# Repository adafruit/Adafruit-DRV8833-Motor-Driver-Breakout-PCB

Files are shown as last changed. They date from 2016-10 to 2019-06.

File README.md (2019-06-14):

## Adafruit DRV8833 Motor Driver Breakout PCB

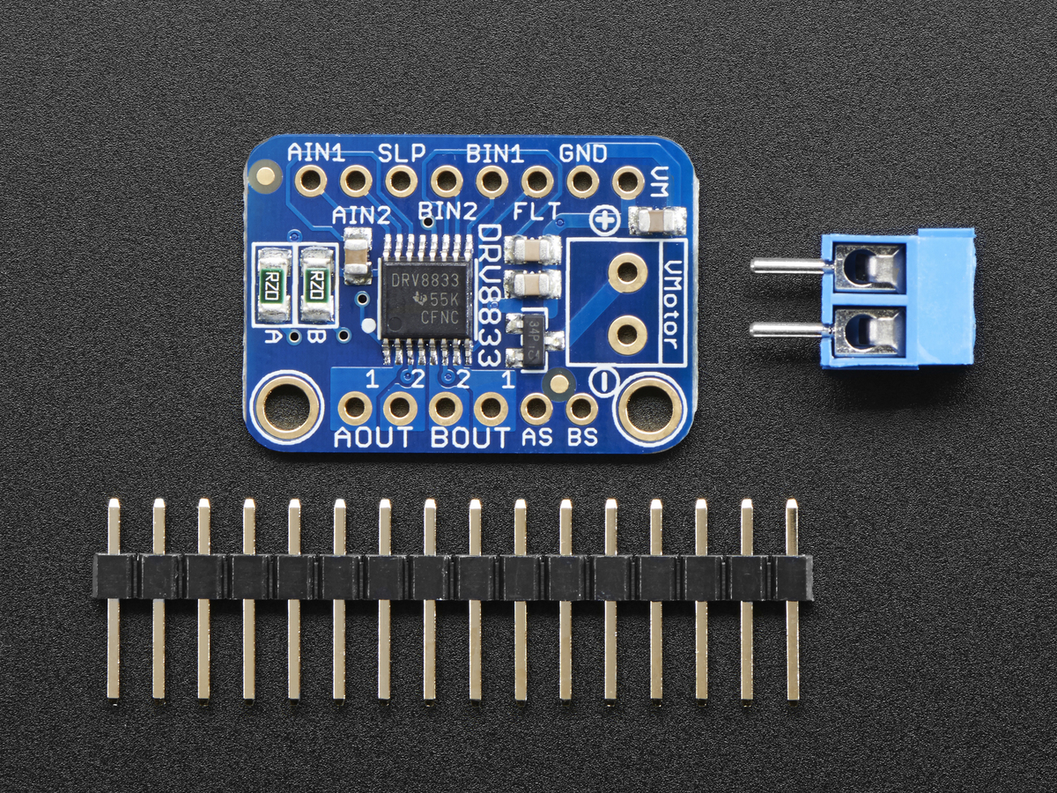
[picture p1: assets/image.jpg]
<a href="http://www.adafruit.com/products/3297"><br/>
Click here to purchase one from the Adafruit shop</a>

PCB files for the Adafurit DRV8833 Motor Driver Breakout. Format is EagleCAD schematic and board layout
* https://www.adafruit.com/product/3297

### DESCRIPTION
Spin two DC motors or step one bi-polar or uni-polar stepper with up to 1.2A per channel using the DRV8833. This motor driver chip is a nice alternative to the TB6612 driver. Like that chip, you get 2 full H-bridges, but this chip is better for low voltage uses (can run from 2.7V up to 10.8V motor power) and has built in current limiting capability. We set it up for 1A current limiting so you don't get more than 2A per chip, but you can also disable the current limiting, or change it to a different limit!

We solder on DRV8833 onto a breakout board for you here, with a polarity protection FET on the motor voltage input. Each breakout chip contains two full H-bridges (four half H-bridges). That means you can drive two DC motors bi-directionally, or one stepper motor. Just make sure they're good for about 1.2 Amp or less of current, since that's the limit of this chip. They do handle a peak of 2A but that's just for a short amount of time, if you turn off the current limiting we set. What we like most about this particular driver is that it comes with built in kick-back diodes internally so you dont have to worry about the inductive kick damaging your project or driver! You also don't have to worry as much about burning out the chip with overdriving since there is current limiting.

There's two digital inputs per H-bridge (one for each half of the bridge), you can PWM one of the inputs to control motor speed. Runs at 2.7V-10.8V logic/motor power. The motor voltage is the same as the logic voltage, but logic voltage from 2.7V or greater will work so no need to worry if you are powering the motors from 9V and using 3.3V logic. For higher voltages, check out the TB6612. For much higher voltages and currents check out the DRV8871!

### License

Adafruit invests time and resources providing this open source design, please support Adafruit and open-source hardware by purchasing products from [Adafruit.com](https://www.adafruit.com)!

Creative Commons Attribution, Share-Alike license, check license.txt for more information All text above must be included in any redistribution - 
See license.txt for more information.

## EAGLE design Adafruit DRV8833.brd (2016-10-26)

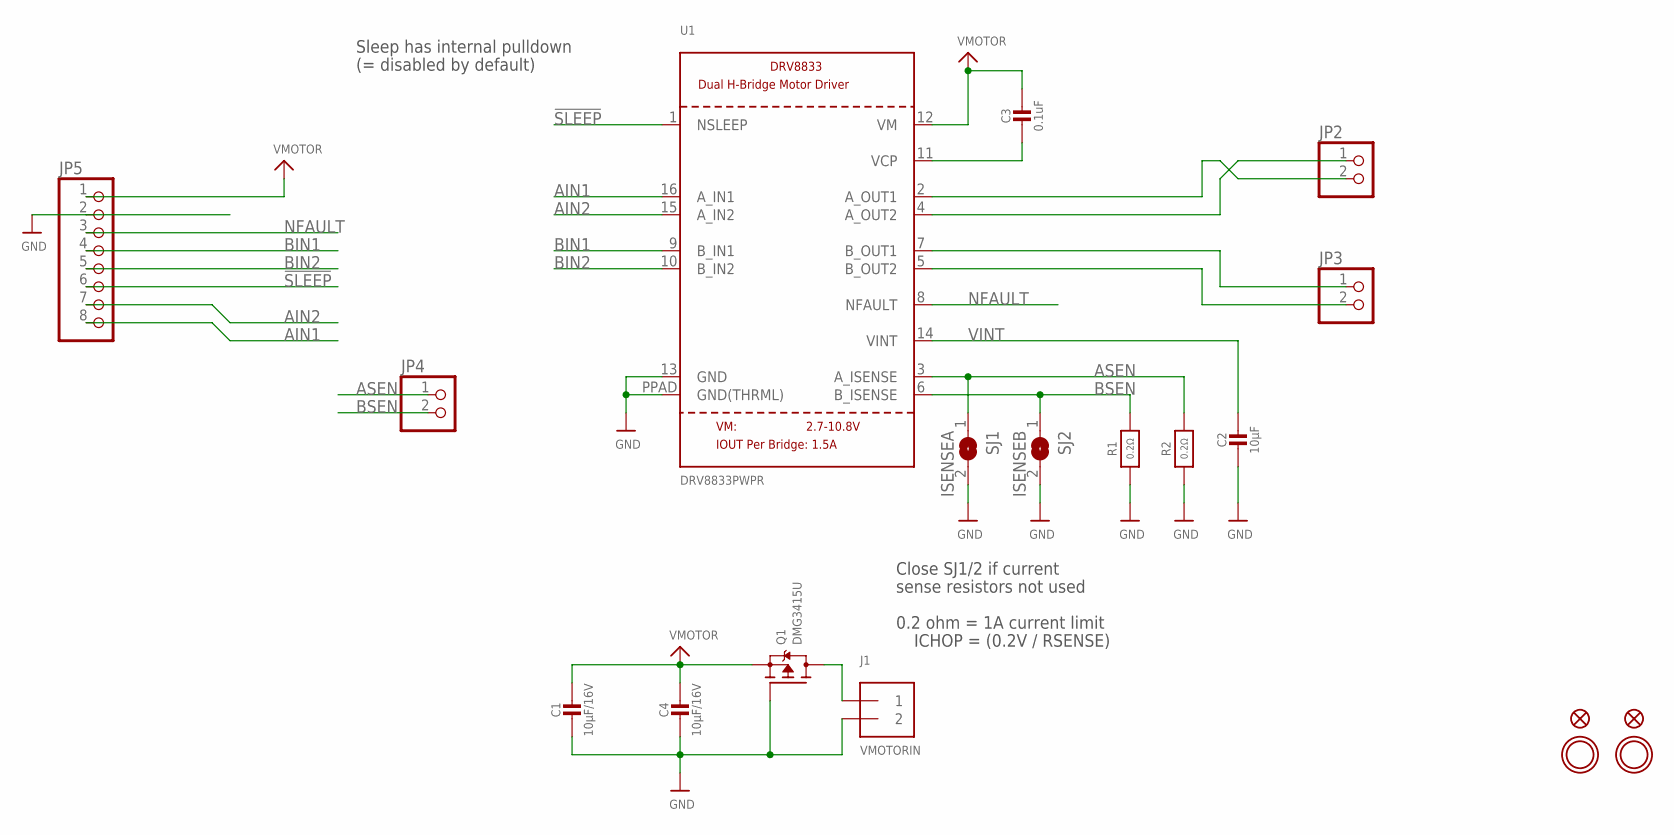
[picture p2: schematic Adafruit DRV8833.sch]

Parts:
C1, C4: 10µF/16V; 0805-NO
C2: 10µF; 0805-NO
C3: 0.1uF; 0805-NO
FID1, FID2: FIDUCIAL""; FIDUCIAL_1MM
J1: VMOTORIN; TERMBLOCK_1X2-3.5MM
JP2, JP3, JP4: HEADER-1X2ROUND; 1X02_ROUND
JP5: HEADER-1X870MIL; 1X08_ROUND_70
Q1: DMG3415U; SOT23-WIDE
R1, R2: 0.2Ω; _1206
SJ1: ISENSEA; SOLDERJUMPER_ARROW_NOPASTE
SJ2: ISENSEB; SOLDERJUMPER_ARROW_NOPASTE
U1: DRV8833PWPR; HTSSOP16
U$13, U$14: MOUNTINGHOLE2.5; MOUNTINGHOLE_2.5_PLATED

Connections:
!SLEEP: JP5.6, U1.1 (NSLEEP)
AIN1: JP5.8, U1.16 (A_IN1)
AIN2: JP5.7, U1.15 (A_IN2)
AOUT1: JP2.2, U1.2 (A_OUT1)
AOUT2: JP2.1, U1.4 (A_OUT2)
ASEN: JP4.1, R2.2, SJ1.1, U1.3 (A_ISENSE)
BIN1: JP5.4, U1.9 (B_IN1)
BIN2: JP5.5, U1.10 (B_IN2)
BOUT1: JP3.1, U1.7 (B_OUT1)
BOUT2: JP3.2, U1.5 (B_OUT2)
BSEN: JP4.2, R1.2, SJ2.1, U1.6 (B_ISENSE)
GND: C1.2, C2.2, C4.2, J1.2, JP5.2, Q1.1 (G), R1.1, R2.1, SJ1.2, SJ2.2, U1.13 (GND), U1.PPAD (GND(THRML))
unnamed: C3.2, U1.11 (VCP)
NFAULT: JP5.3, U1.8 (NFAULT)
PWRIN: J1.1, Q1.3 (D)
VINT: C2.1, U1.14 (VINT)
VMOTOR: C1.1, C3.1, C4.1, JP5.1, Q1.2 (S), U1.12 (VM)

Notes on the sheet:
Close SJ1/2 if current
sense resistors not used
0.2 ohm = 1A current limit
ICHOP = (0.2V / RSENSE)
Sleep has internal pulldown
(= disabled by default)

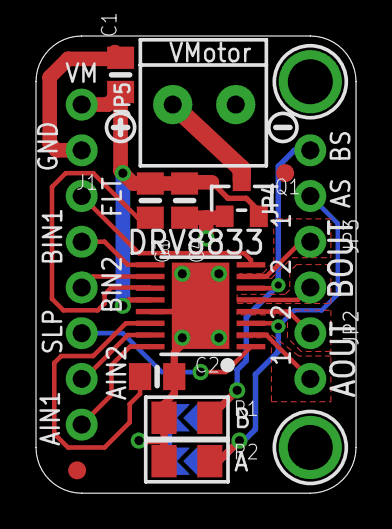
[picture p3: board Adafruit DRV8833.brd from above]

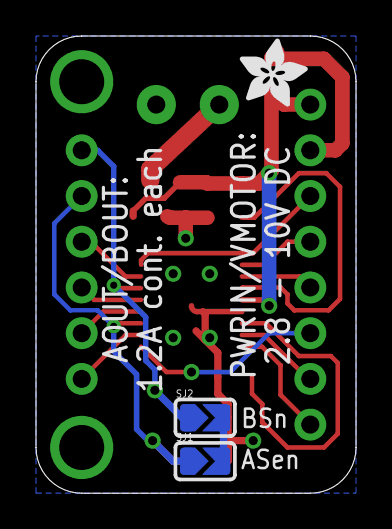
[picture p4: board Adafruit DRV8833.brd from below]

Board: 2 copper layers, 17.8 x 25.4 mm, 22 parts (3 on the bottom side), 17 nets.

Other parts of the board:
U$15: SYMBOL_PLUS
U$16: SYMBOL_MINUS
U$17: ADAFRUIT_3.5MM
